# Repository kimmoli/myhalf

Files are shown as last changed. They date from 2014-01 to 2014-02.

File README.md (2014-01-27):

MYHALF v1.10
======

Otherhalf breakout board for Jolla

Bill of materials

R1, R2  0603 2k15 (or 2k2) I2C 3.3V pullups. I usually use 2k15 from E96 series.

R3      0603 330 ohms or something like that for led series resistor

C1, C2  0603 1µF 16V X7R

H1      0603 Led of your favorite colour (for blue or white, change R3)

N1      MCP1700-1802E (Microchip) in SOT23 1.8V Regulator

D1      PCA9517DGKR (TI) in MSOP8 (or PCA9517DP (NXP) in TSSOP-8) I2C Level translator
        http://www.nxp.com/documents/data_sheet/PCA9517.pdf
        
D3      AT24C02D-STUM-T (Atmel) in SOT23-5 I2C EEPROM 2kbit
        http://www.atmel.com/Images/Atmel-8871-SEEPROM-AT24C01D-02D-Datasheet.pdf
        
X1      2.54mm (0.1") pinheader 10 pins, or just solder wires

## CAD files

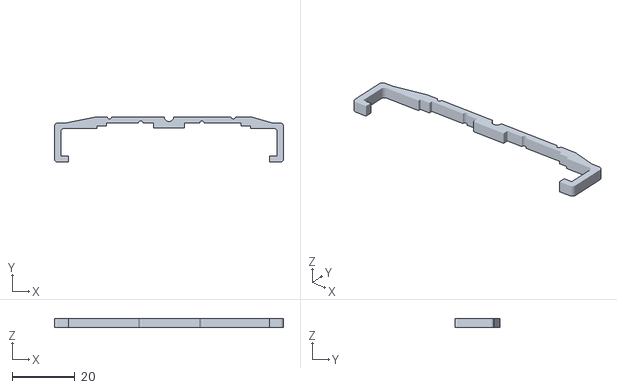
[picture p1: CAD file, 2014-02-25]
Myhalf-clip-08mm.stl
73.0 x 14.5 x 3.00

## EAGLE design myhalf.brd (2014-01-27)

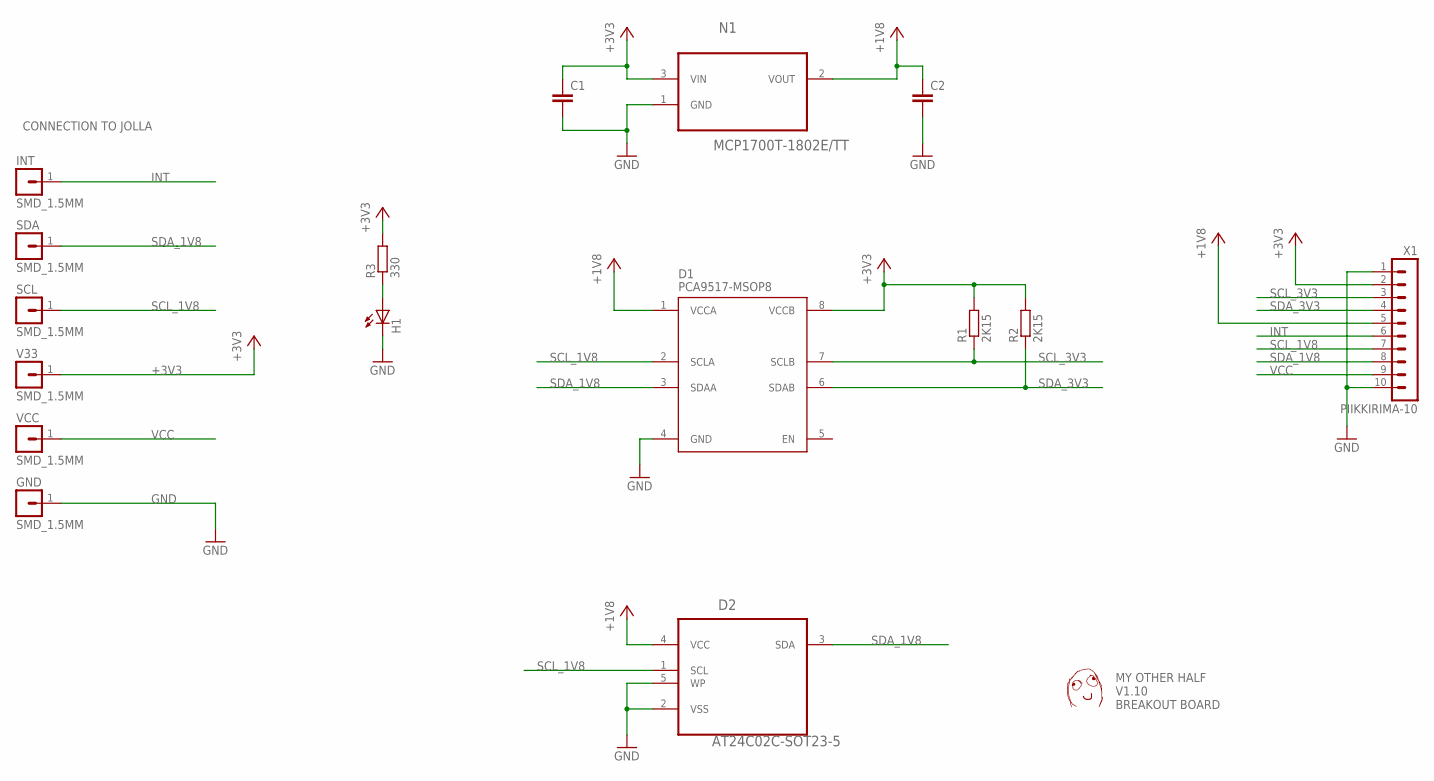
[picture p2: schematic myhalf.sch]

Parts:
C1, C2: C-EUC0603; C0603
D1: PCA9517-MSOP8; SOP65P490X110-8N
D2: AT24C02C-SOT23-5; SOT95P280X145-5N
GND: SMD_1.5MM; SMD_ROUND_1.5MM
H1: LEDCHIP-LED0603; CHIP-LED0603
INT: SMD_1.5MM; SMD_ROUND_1.5MM
N1: MCP1700T-1802E/TT; SOT95P237X112-3N
R1, R2: 2K15; R0603
R3: 330; R0603
SCL: SMD_1.5MM; SMD_ROUND_1.5MM
SDA: SMD_1.5MM; SMD_ROUND_1.5MM
U$1: DAFUG
V33: SMD_1.5MM; SMD_ROUND_1.5MM
VCC: SMD_1.5MM; SMD_ROUND_1.5MM
X1: PIIKKIRIMA-10

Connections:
+1V8: C2.1, D1.1 (VCCA), D2.4 (VCC), N1.2 (VOUT), X1.5
+3V3: C1.1, D1.8 (VCCB), N1.3 (VIN), R1.2, R2.2, R3.2, V33.1, X1.2
GND: C1.2, C2.2, D1.4 (GND), D2.2 (VSS), D2.5 (WP), GND.1, H1.C, N1.1 (GND), X1.1, X1.10
INT: INT.1, X1.6
unnamed: H1.A, R3.1
SCL_1V8: D1.2 (SCLA), D2.1 (SCL), SCL.1, X1.7
SCL_3V3: D1.7 (SCLB), R1.1, X1.3
SDA_1V8: D1.3 (SDAA), D2.3 (SDA), SDA.1, X1.8
SDA_3V3: D1.6 (SDAB), R2.1, X1.4
VCC: VCC.1, X1.9

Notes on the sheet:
MY OTHER HALF V1.10 BREAKOUT BOARD
CONNECTION TO JOLLA

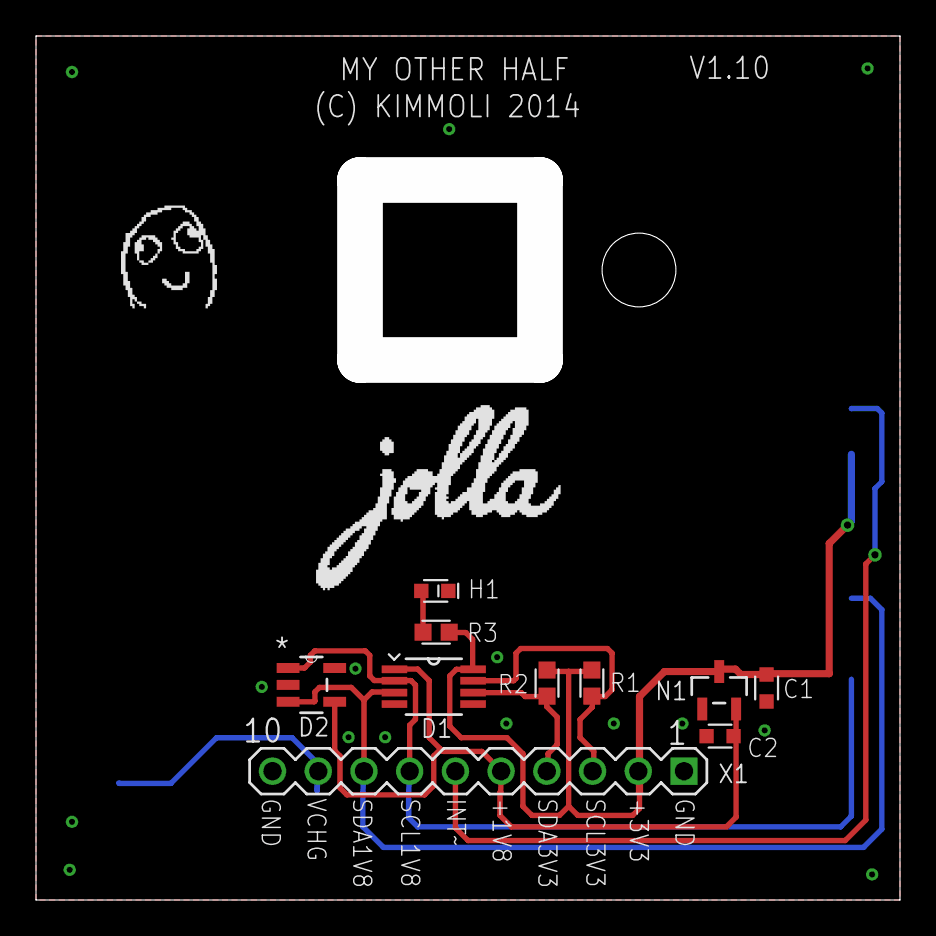
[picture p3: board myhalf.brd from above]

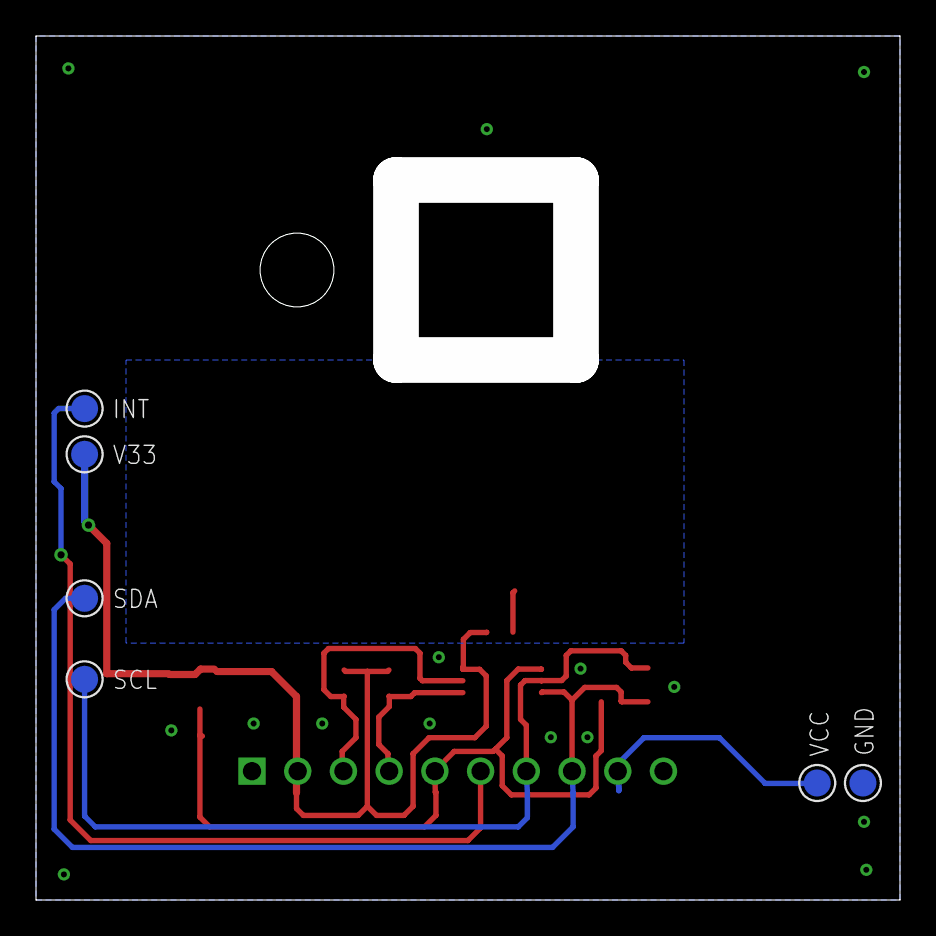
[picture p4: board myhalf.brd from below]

Board: 2 copper layers, 48.0 x 48.0 mm, 18 parts (6 on the bottom side), 10 nets.

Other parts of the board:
U$2: JOLLALOGO

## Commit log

2013-12-14 pogo-mating pads placed, outline drawn
    [myhalf.brd, myhalf.sch]
2013-12-14 some more work progress...
    [myhalf.brd, myhalf.sch]
2013-12-14 good night
    [myhalf.brd, myhalf.sch]
2014-02-20 Clip STL for 0.8mm pcb added
    [Myhalf-clip-08mm.stl]
2014-02-25 Clip modified, clearance to antennas
    [Myhalf-clip-08mm.stl]
